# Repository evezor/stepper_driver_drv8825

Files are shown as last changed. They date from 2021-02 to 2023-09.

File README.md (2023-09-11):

# DRV8825 Stepper Motor Driver V1.0

*please note this board has been deprecated.

This board uses the Evezor Stamp STMF405 MCU

source: https://github.com/evezor/Evezor-Stamp-STMF405

An edge board with a DRV8825 stepper motor driver, limit switch connections and encoder inputs 

source files: https://github.com/evezor/v0_stepper_driver_drv8825

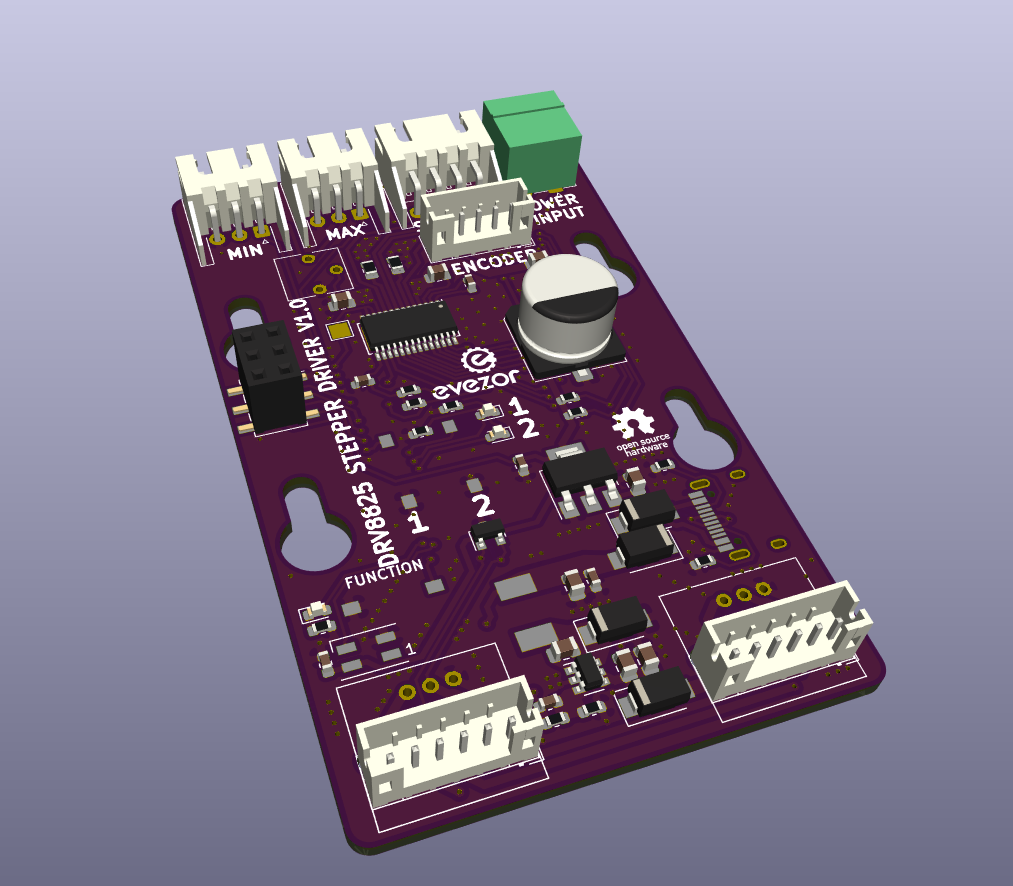
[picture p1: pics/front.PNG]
front


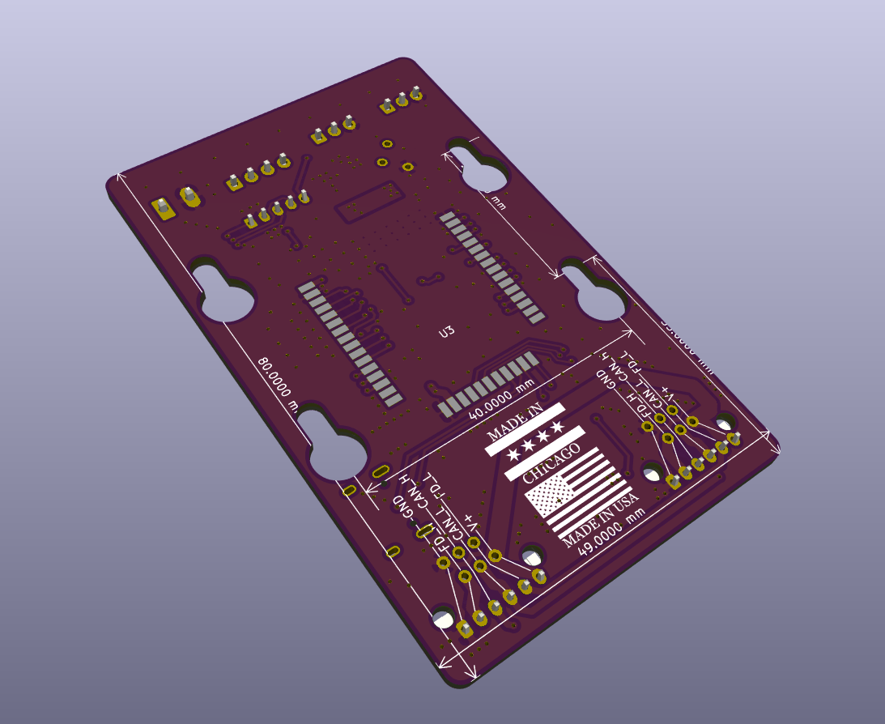
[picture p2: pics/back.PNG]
back


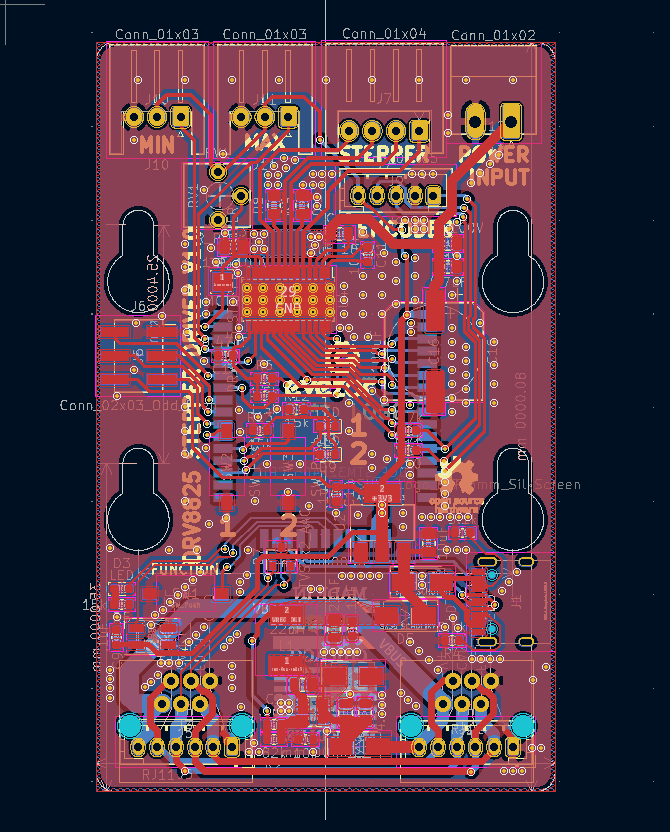
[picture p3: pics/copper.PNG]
copper


Evezor® and all associated marks, logos, and designs are registered trademarks and protected by copyright. Unauthorized use or reproduction of these trademarks and copyrighted materials is strictly prohibited.

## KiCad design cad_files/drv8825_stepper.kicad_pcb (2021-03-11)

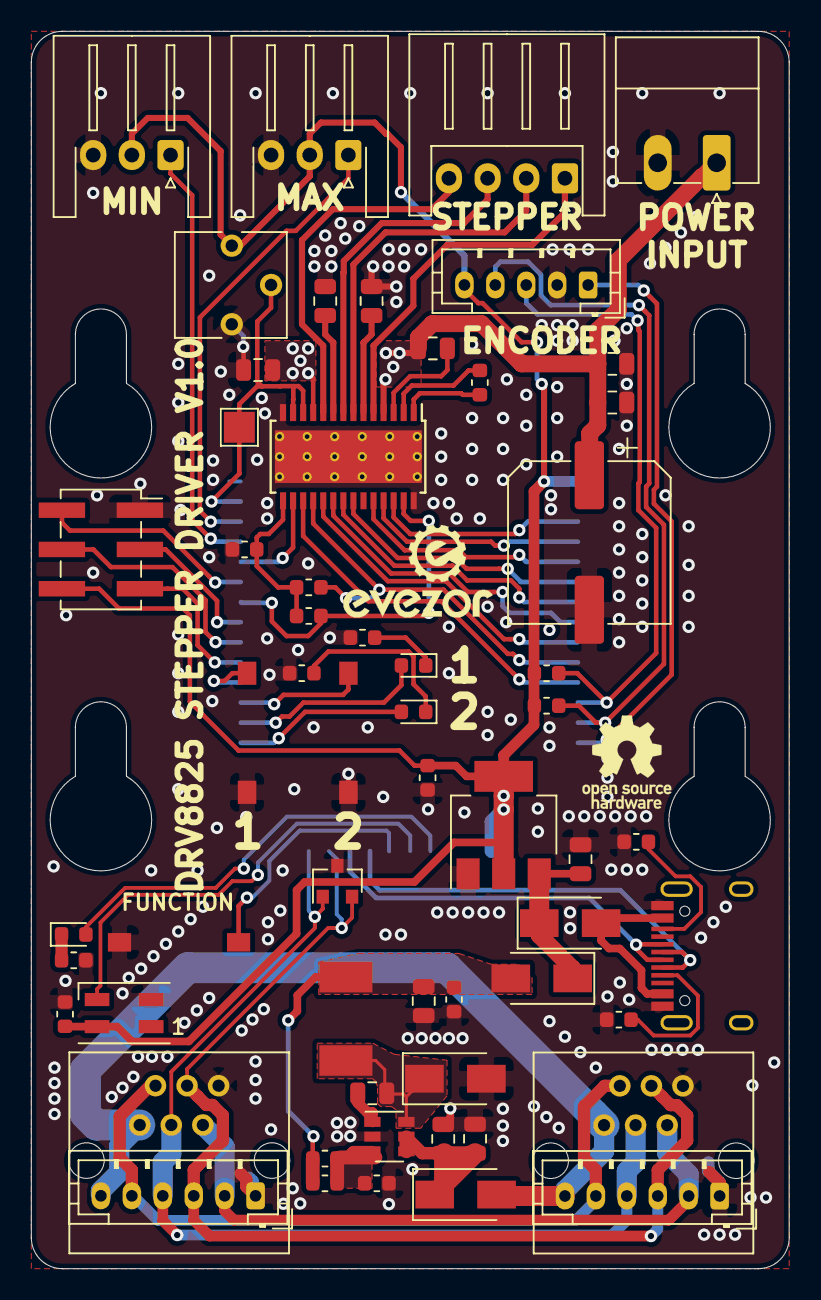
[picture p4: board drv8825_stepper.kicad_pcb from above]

Board: 2 copper layers, 49.0 x 80.0 mm, 59 parts (1 on the bottom side), 60 nets.

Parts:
C1, C3, C12, C13, C15: .1uF 100V; C_0805_2012Metric
C2, C5, C9, C10: .1uF; C_0603_1608Metric
C4, C7: 4.7uF; C_0805_2012Metric
C6: 22uF; C_0805_2012Metric
C8: 10uF; C_0805_2012Metric
C11: 10 nF; C_0603_1608Metric
C14: 0.47uF; C_0603_1608Metric
C16: 100uF; CP_Elec_10x7.7
D1, D2, D4, D5: SX35_SCHOTTKY; D_SMA
D3, D8, D9: LED; LED_0603_1608Metric
D6: SK6812MINI; LED_SK6812MINI_PLCC4_3.5x3.5mm_P1.75mm
D7: D_TVS_x2_AAC; SOT-23
J1: USB_C_Receptacle_USB2.0; USB_C_Receptacle_HRO_TYPE-C-31-M-12
J2, J3: RJ11; RJ11_C189747_Horizontal
J4, J5: PH; JST_PH_B6B-PH-K_1x06_P2.00mm_Vertical
J6: Conn_02x03_Odd_Even; PinSocket_2x03_P2.54mm_Vertical_SMD
J7: Conn_01x04; JST_XH_S4B-XH-A_1x04_P2.50mm_Horizontal
J9: Conn_01x05; JST_PH_B5B-PH-K_1x05_P2.00mm_Vertical
J10, J11: Conn_01x03; JST_XH_S3B-XH-A-1_1x03_P2.50mm_Horizontal
J12: Conn_01x02; PhoenixContact_MC_1,5_2-G-3.81_1x02_P3.81mm_Horizontal
L1: 22uH; INDUCTOR_7.5X6.6_GCDA0630-220MC
R1: 10k; R_0603_1608Metric
R2: 82k; R_0603_1608Metric
R3, R4: 5.1k; R_0603_1608Metric
R5, R12, R13: 15k; R_0603_1608Metric
R6, R7: 1.5k; R_0603_1608Metric
R8, R9: 0.1; R_0805_2012Metric
R10, R11: 4.7k; R_0603_1608Metric
RV1: R_POT; Potentiometer_Vishay_T73YP_Vertical
SW1, SW2, SW3: SW_Push; SWITCH_2x3_SMD_TACTILE_GREEN
TP1: MCTP; TestPoint_Pad_2.0x2.0mm
U1: SY8401ABC; SOT-23-6
U2: AMS1117-3.3; SOT-223-3_TabPin2
U3: EDGE_STM32F405_CPU_V1; EDGE_STAMP
U4: DRV8825_STEPPER_DRIVER; HTSSOP-28-1EP_4.4x9.7mm_P0.65mm_EP3.4x9.5mm_ThermalVias

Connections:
+3V3: C9.2, C10.1, D6.4, J6.6, J9.5, J10.2, J11.2, R10.2, R11.2, RV1.3, U2.2, U3.1, U3.18
/BOOT: J6.3, U3.36
/BUTTON_1: SW2.1, U3.33
/BUTTON_2: SW3.1, U3.32
/CAN_H: D7.2, J2.3, J3.3, J4.3, J5.3, U3.26
/CAN_L: D7.1, J2.4, J3.4, J4.4, J5.4, U3.27
/CC1: J1.A5, R4.1
/CC2: J1.B5, R3.1
/CURRENT_REF: RV1.2, TP1.1, U3.42, U4.12, U4.13
/D+: J1.A6, J1.B6, U3.25
/D-: J1.A7, J1.B7, U3.24
/DECAY: U3.9, U4.19
/DIR: U3.8, U4.20
/ENABLE: U3.7, U4.21
/ENCDR_NEO: J9.1, U3.14
/FAULT: R6.2, U3.10, U4.18
/FD_H: J2.2, J3.2, J4.2, J5.2
/FD_L: J2.5, J3.5, J4.5, J5.5
/FUNCTION_BUTTON: SW1.1, U3.23
/HBT_LED: D3.2, U3.21
/HOME: R7.2, U3.37, U4.27
/LED_1: D8.2, U3.31
/LED_2: D9.2, U3.30
/M0: U3.5, U4.24
/M1: U3.4, U4.25
/M2: U3.3, U4.26
/MAX: J11.1, U3.41
/MIN: J10.1, U3.40
/NEO_STATUS: D6.3, U3.22
/OLED_SCL: J6.5, U3.34
/OLED_SDA: J6.4, U3.35
/RESET: J6.2, U3.38
/SCL: J9.3, R11.1, U3.12
/SDA: J9.4, R10.1, U3.13
/SLEEP: U3.11, U4.17
/STEP: U3.6, U4.22
/S_RESET: U3.39, U4.16
/USB_VCC: D4.2, J1.A4, J1.A9, J1.B4, J1.B9
/V3P3: C14.1, R6.1, R7.1, U4.15
/VREG_OUT: C2.1, C5.1, C6.1, D5.2, L1.2, R2.1
/V_MOTOR: C7.1, C12.2, C13.2, C15.1, C16.1, J12.1, U4.4, U4.11
GND: C3.2, C4.2, C5.2, C6.2, C7.2, C8.2, C9.1, C10.2, C12.1, C13.1, C14.2, C16.2, D1.2, D6.2, D7.3, J1.A1, J1.A12, J1.B1, J1.B12, J2.1, J3.1, J4.1, J5.1, J6.1, J9.2, J10.3, J11.3, J12.2, R1.1, R3.2, R4.2, R5.1, R8.2, R9.2, R12.1, R13.1, RV1.1, SW1.2, SW2.2, SW3.2, U1.2, U2.1, U3.2, U3.17, U3.43, U4.14, U4.28, U4.29
unnamed: C1.1, D1.1, L1.1, U1.6
unnamed: C1.2, U1.1
unnamed: C2.2, R1.2, R2.2, U1.3
unnamed: C3.1, C4.1, D2.1, U1.4, U1.5
unnamed: C8.1, D4.1, D5.1, U2.3
unnamed: C11.1, U4.2
unnamed: C11.2, U4.1
unnamed: C15.2, U4.3
unnamed: D3.1, R5.2
unnamed: D8.1, R12.2
unnamed: D9.1, R13.2
unnamed: J7.1, U4.5
unnamed: J7.2, U4.7
unnamed: J7.3, U4.8
unnamed: J7.4, U4.10
unnamed: R8.1, U4.9
unnamed: R9.1, U4.6
VBUS: D2.2, J2.6, J3.6, J4.6, J5.6

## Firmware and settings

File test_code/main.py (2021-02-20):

#DRV8825 temporary test board

from machine import Pin
from pyb import CAN
import utime


# Needed inputs/ outputs

# Left side:
# set_position
# set_offset example: @some_value saw cuts a 50mm piece
# go_home
# set_speed
# set_acceleration
# set_positive_direction
# set_steps_per_millimeter = 13.3333333
# inactivity_timeout  example: turns off motor after set amount of time


# Right Side:
# is_homed
# low_limit_switch
# high_limit_switch
# motor_is_enabled


move_delay = 450


HBT_LED = Pin("D13", Pin.OUT)
FUNC_BUTTON = Pin("D5", Pin.IN, Pin.PULL_UP) 

DIR_PIN = Pin("A0", Pin.OUT)
STEP_PIN = Pin("A2", Pin.OUT)
ENABLE_PIN = Pin("A4", Pin.OUT)
LIMIT_PIN = Pin("D0", Pin.IN, Pin.PULL_UP)


DIR_PIN.value(0) #set initial direction
ENABLE_PIN.value(1) #turn motor driver off

    #Setup hbt timer
hbt_state = 0
hbt_interval = 500
start = utime.ticks_ms()
next_hbt = utime.ticks_add(start, hbt_interval)
HBT_LED.value(hbt_state)


print("starting Devboard")


def chk_hbt():
    global next_hbt
    global hbt_state
    now = utime.ticks_ms()
    if utime.ticks_diff(next_hbt, now) <= 0:
        if hbt_state == 1:
            hbt_state = 0
            HBT_LED.value(hbt_state)
            #print("hbt")
        else:
            hbt_state = 1
            HBT_LED.value(hbt_state)  
        
        next_hbt = utime.ticks_add(next_hbt, hbt_interval)

def enable():
    ENABLE_PIN.value(0)
    
def disable():
    ENABLE_PIN.value(1)
    
def move():
    print("doing move thing")
    DIR_PIN.value(1)
    enable()
    utime.sleep_ms(1)
    for i in range(4800):
        STEP_PIN.value(1)
        #utime.sleep_ms(move_delay)
        STEP_PIN.value(0)
        utime.sleep_us(move_delay)
    DIR_PIN.value(0)
    utime.sleep_ms(1)
    for i in range(4800):
        STEP_PIN.value(1)
        #utime.sleep_ms(move_delay)
        STEP_PIN.value(0)
        utime.sleep_us(move_delay)
    disable()
        
while True:
    chk_hbt()
    if not (FUNC_BUTTON.value()):
        print("function button")
        utime.sleep_ms(200)
    if (LIMIT_PIN.value()):
        print("limit switch")
        move()
        utime.sleep_ms(500)
